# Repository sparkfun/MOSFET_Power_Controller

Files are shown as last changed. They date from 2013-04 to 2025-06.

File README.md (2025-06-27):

MOSFET Power Controller
=======================

[MOSFET Power Controller  
*MOSFET Power Controller(PRT-11214)*](https://www.sparkfun.com/products/11214)

This MOSFET Power Controller board allows you to turn a high current battery power supply on and off via microcontroller inputs. 

Repository Contents
-------------------
* **/Hardware** - All Eagle design files (.brd, .sch)
* **/Production** - Test bed files and production panel files

License Information
-------------------
The hardware is released under [Creative Commons Share-alike 3.0](http://creativecommons.org/licenses/by-sa/3.0/).

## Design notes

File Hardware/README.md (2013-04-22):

# What Are these Files?

The .sch and .brd files hare are Eagle CAD schematic and PCB design files.

These files were created with Eagle 6.3.0, you'll need Eagle 6.3 or later to open them up. There is a free, lite, version of Eagle available from [cadsoftusa.com](cadsoftusa.com).

# License

This product is open source! These Eagle files are released under the Creative Commons Share-Alike Attribution license ([CC BY-SA 3.0](http://creativecommons.org/licenses/by-sa/3.0/us/)).

Please use, reuse, and modify these files as you see fit. Please maintain attribution and release anything derivative under the same license.

- Your friends at SparkFun.

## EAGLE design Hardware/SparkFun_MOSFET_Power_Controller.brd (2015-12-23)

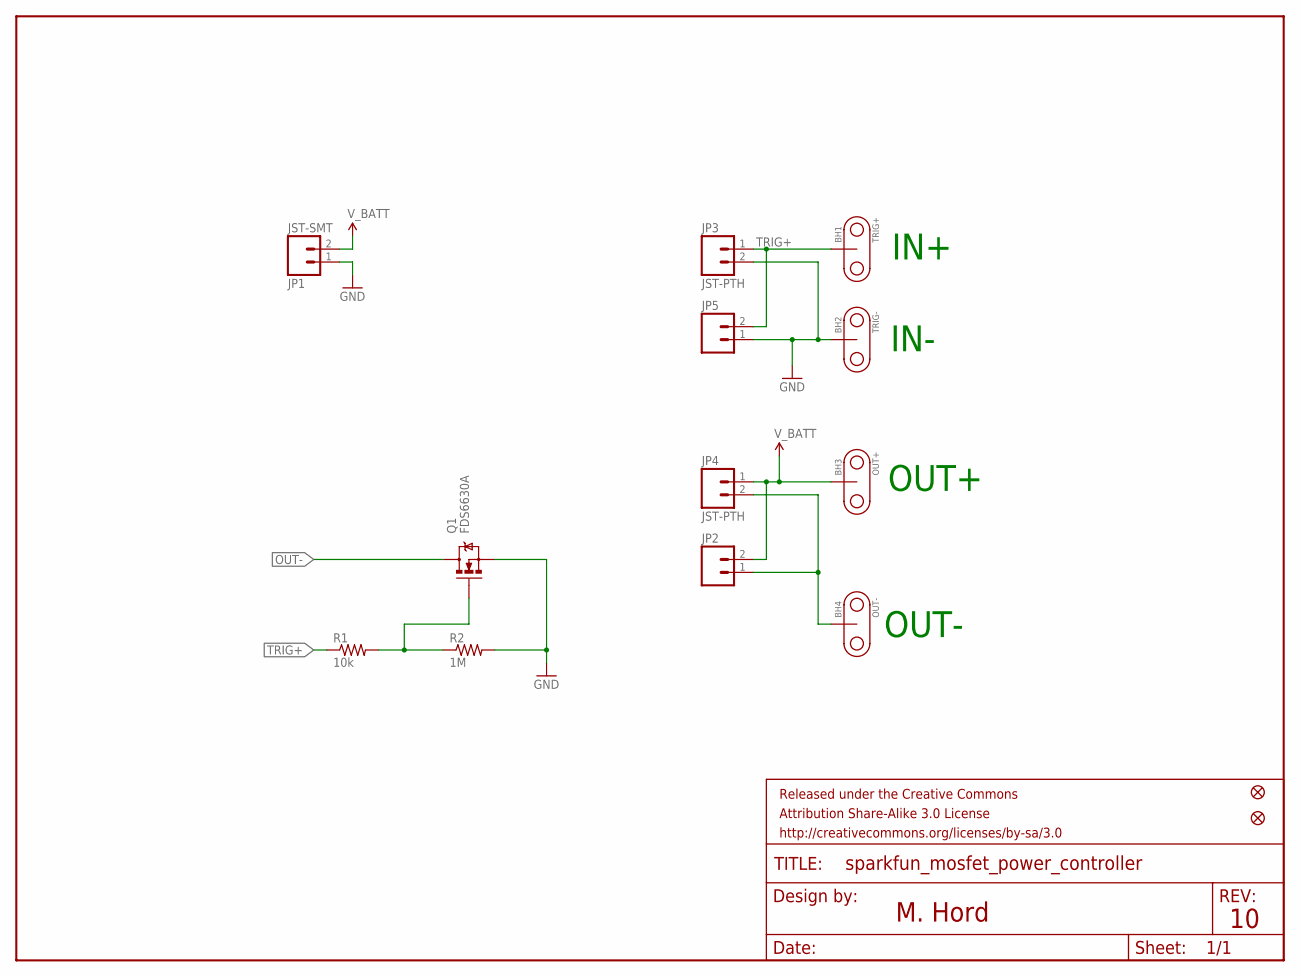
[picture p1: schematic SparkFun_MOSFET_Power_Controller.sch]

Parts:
BH1: TRIG+; BUTTONHOLE
BH2: TRIG-; BUTTONHOLE
BH3: OUT+; BUTTONHOLE
BH4: OUT-; BUTTONHOLE
FRAME1: FRAME-LETTER; CREATIVE_COMMONS
JP1: JST-SMT; JST-2-SMD
JP2, JP5: M02PTH; 1X02
JP3, JP4: JST-PTH; JST-2-PTH-NS
JP6, JP7: FIDUCIALUFIDUCIAL; MICRO-FIDUCIAL
Q1: FDS6630A; SO08
R1: 10k; 0402-RES
R2: 1M; 0402-RES

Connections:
GND: BH2.P$1, JP1.1 (2), JP3.2, JP5.1, Q1.1 (S), Q1.2 (S), Q1.3 (S), R2.2
unnamed: Q1.4 (G), R1.2, R2.1
OUT-: BH4.P$1, JP2.1, JP4.2, Q1.5 (D), Q1.6 (D), Q1.7 (D), Q1.8 (D)
TRIG+: BH1.P$1, JP3.1, JP5.2, R1.1
V_BATT: BH3.P$1, JP1.2 (1), JP2.2, JP4.1

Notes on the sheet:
M. Hord
IN+
IN-
OUT+
OUT-

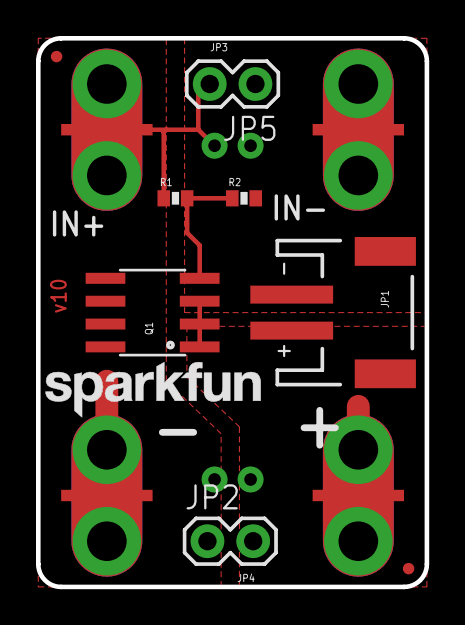
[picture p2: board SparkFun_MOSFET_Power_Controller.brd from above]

Board: 2 copper layers, 21.6 x 30.5 mm, 15 parts (0 on the bottom side), 5 nets.

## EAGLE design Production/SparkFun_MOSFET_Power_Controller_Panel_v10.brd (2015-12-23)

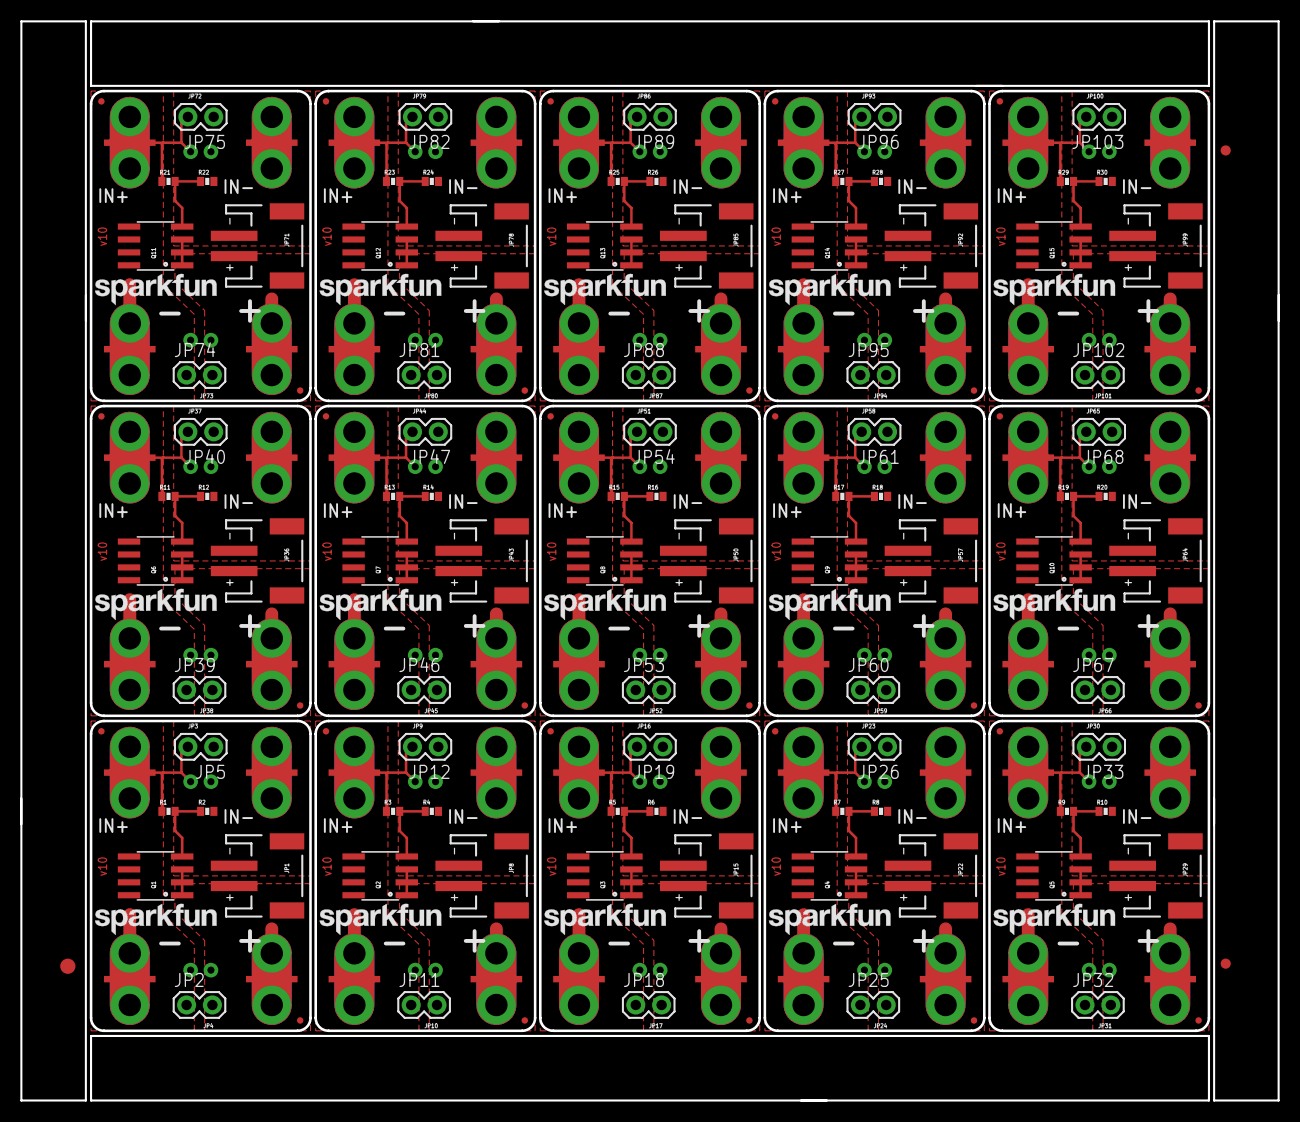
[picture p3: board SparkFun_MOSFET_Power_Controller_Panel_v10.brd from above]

Board: 2 copper layers, 123.7 x 106.2 mm, 213 parts (0 on the bottom side), 75 nets.

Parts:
BH1, BH5, BH9, BH13, BH17, BH21, BH25, BH29, BH33, BH37, BH41, BH45, BH49, BH53, BH57: TRIG+; BUTTONHOLE
BH2, BH6, BH10, BH14, BH18, BH22, BH26, BH30, BH34, BH38, BH42, BH46, BH50, BH54, BH58: TRIG-; BUTTONHOLE
BH3, BH7, BH11, BH15, BH19, BH23, BH27, BH31, BH35, BH39, BH43, BH47, BH51, BH55, BH59: OUT+; BUTTONHOLE
BH4, BH8, BH12, BH16, BH20, BH24, BH28, BH32, BH36, BH40, BH44, BH48, BH52, BH56, BH60: OUT-; BUTTONHOLE
E$1: FIDUCIAL-1.5X3
E$5, E$6: FIDUCIAL-1X2
JP1, JP8, JP15, JP22, JP29, JP36, JP43, JP50, JP57, JP64, JP71, JP78, JP85, JP92, JP99: JST-SMT; JST-2-SMD
JP2, JP5, JP11, JP12, JP18, JP19, JP25, JP26, JP32, JP33, JP39, JP40, JP46, JP47, JP53, JP54, JP60, JP61, JP67, JP68, JP74, JP75, JP81, JP82, JP88, JP89, JP95, JP96, JP102, JP103: 1X02
JP3, JP4, JP9, JP10, JP16, JP17, JP23, JP24, JP30, JP31, JP37, JP38, JP44, JP45, JP51, JP52, JP58, JP59, JP65, JP66, JP72, JP73, JP79, JP80, JP86, JP87, JP93, JP94, JP100, JP101: JST-PTH; JST-2-PTH-NS
JP6, JP7, JP13, JP14, JP20, JP21, JP27, JP28, JP34, JP35, JP41, JP42, JP48, JP49, JP55, JP56, JP62, JP63, JP69, JP70, JP76, JP77, JP83, JP84, JP90, JP91, JP97, JP98, JP104, JP105: FIDUCIALUFIDUCIAL; MICRO-FIDUCIAL
Q1, Q2, Q3, Q4, Q5, Q6, Q7, Q8, Q9, Q10, Q11, Q12, Q13, Q14, Q15: FDS6630A; SO08
R1, R3, R5, R7, R9, R11, R13, R15, R17, R19, R21, R23, R25, R27, R29: 10k; 0402-RES
R2, R4, R6, R8, R10, R12, R14, R16, R18, R20, R22, R24, R26, R28, R30: 1M; 0402-RES

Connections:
GND: BH2.P$1, JP1.1, JP3.2, JP5.1, Q1.1, Q1.2, Q1.3, R2.2
GND1: BH6.P$1, JP8.1, JP9.2, JP12.1, Q2.1, Q2.2, Q2.3, R4.2
GND2: BH10.P$1, JP15.1, JP16.2, JP19.1, Q3.1, Q3.2, Q3.3, R6.2
GND3: BH14.P$1, JP22.1, JP23.2, JP26.1, Q4.1, Q4.2, Q4.3, R8.2
GND4: BH18.P$1, JP29.1, JP30.2, JP33.1, Q5.1, Q5.2, Q5.3, R10.2
GND5: BH22.P$1, JP36.1, JP37.2, JP40.1, Q6.1, Q6.2, Q6.3, R12.2
GND6: BH26.P$1, JP43.1, JP44.2, JP47.1, Q7.1, Q7.2, Q7.3, R14.2
GND7: BH30.P$1, JP50.1, JP51.2, JP54.1, Q8.1, Q8.2, Q8.3, R16.2
GND8: BH34.P$1, JP57.1, JP58.2, JP61.1, Q9.1, Q9.2, Q9.3, R18.2
GND9: BH38.P$1, JP64.1, JP65.2, JP68.1, Q10.1, Q10.2, Q10.3, R20.2
GND10: BH42.P$1, JP71.1, JP72.2, JP75.1, Q11.1, Q11.2, Q11.3, R22.2
GND11: BH46.P$1, JP78.1, JP79.2, JP82.1, Q12.1, Q12.2, Q12.3, R24.2
GND12: BH50.P$1, JP85.1, JP86.2, JP89.1, Q13.1, Q13.2, Q13.3, R26.2
GND13: BH54.P$1, JP92.1, JP93.2, JP96.1, Q14.1, Q14.2, Q14.3, R28.2
GND14: BH58.P$1, JP99.1, JP100.2, JP103.1, Q15.1, Q15.2, Q15.3, R30.2
unnamed: Q1.4, R1.2, R2.1
unnamed: Q2.4, R3.2, R4.1
unnamed: Q3.4, R5.2, R6.1
unnamed: Q4.4, R7.2, R8.1
unnamed: Q5.4, R9.2, R10.1
unnamed: Q6.4, R11.2, R12.1
unnamed: Q7.4, R13.2, R14.1
unnamed: Q8.4, R15.2, R16.1
unnamed: Q9.4, R17.2, R18.1
unnamed: Q10.4, R19.2, R20.1
unnamed: Q11.4, R21.2, R22.1
unnamed: Q12.4, R23.2, R24.1
unnamed: Q13.4, R25.2, R26.1
unnamed: Q14.4, R27.2, R28.1
unnamed: Q15.4, R29.2, R30.1
OUT-: BH4.P$1, JP2.1, JP4.2, Q1.5, Q1.6, Q1.7, Q1.8
OUT-1: BH8.P$1, JP10.2, JP11.1, Q2.5, Q2.6, Q2.7, Q2.8
OUT-2: BH12.P$1, JP17.2, JP18.1, Q3.5, Q3.6, Q3.7, Q3.8
OUT-3: BH16.P$1, JP24.2, JP25.1, Q4.5, Q4.6, Q4.7, Q4.8
OUT-4: BH20.P$1, JP31.2, JP32.1, Q5.5, Q5.6, Q5.7, Q5.8
OUT-5: BH24.P$1, JP38.2, JP39.1, Q6.5, Q6.6, Q6.7, Q6.8
OUT-6: BH28.P$1, JP45.2, JP46.1, Q7.5, Q7.6, Q7.7, Q7.8
OUT-7: BH32.P$1, JP52.2, JP53.1, Q8.5, Q8.6, Q8.7, Q8.8
OUT-8: BH36.P$1, JP59.2, JP60.1, Q9.5, Q9.6, Q9.7, Q9.8
OUT-9: BH40.P$1, JP66.2, JP67.1, Q10.5, Q10.6, Q10.7, Q10.8
OUT-10: BH44.P$1, JP73.2, JP74.1, Q11.5, Q11.6, Q11.7, Q11.8
OUT-11: BH48.P$1, JP80.2, JP81.1, Q12.5, Q12.6, Q12.7, Q12.8
OUT-12: BH52.P$1, JP87.2, JP88.1, Q13.5, Q13.6, Q13.7, Q13.8
OUT-13: BH56.P$1, JP94.2, JP95.1, Q14.5, Q14.6, Q14.7, Q14.8
OUT-14: BH60.P$1, JP101.2, JP102.1, Q15.5, Q15.6, Q15.7, Q15.8
TRIG+: BH1.P$1, JP3.1, JP5.2, R1.1
TRIG+1: BH5.P$1, JP9.1, JP12.2, R3.1
TRIG+2: BH9.P$1, JP16.1, JP19.2, R5.1
TRIG+3: BH13.P$1, JP23.1, JP26.2, R7.1
TRIG+4: BH17.P$1, JP30.1, JP33.2, R9.1
TRIG+5: BH21.P$1, JP37.1, JP40.2, R11.1
TRIG+6: BH25.P$1, JP44.1, JP47.2, R13.1
TRIG+7: BH29.P$1, JP51.1, JP54.2, R15.1
TRIG+8: BH33.P$1, JP58.1, JP61.2, R17.1
TRIG+9: BH37.P$1, JP65.1, JP68.2, R19.1
TRIG+10: BH41.P$1, JP72.1, JP75.2, R21.1
TRIG+11: BH45.P$1, JP79.1, JP82.2, R23.1
TRIG+12: BH49.P$1, JP86.1, JP89.2, R25.1
TRIG+13: BH53.P$1, JP93.1, JP96.2, R27.1
TRIG+14: BH57.P$1, JP100.1, JP103.2, R29.1
V_BATT: BH3.P$1, JP1.2, JP2.2, JP4.1
V_BATT1: BH7.P$1, JP8.2, JP10.1, JP11.2
V_BATT2: BH11.P$1, JP15.2, JP17.1, JP18.2
V_BATT3: BH15.P$1, JP22.2, JP24.1, JP25.2
V_BATT4: BH19.P$1, JP29.2, JP31.1, JP32.2
V_BATT5: BH23.P$1, JP36.2, JP38.1, JP39.2
V_BATT6: BH27.P$1, JP43.2, JP45.1, JP46.2
V_BATT7: BH31.P$1, JP50.2, JP52.1, JP53.2
V_BATT8: BH35.P$1, JP57.2, JP59.1, JP60.2
V_BATT9: BH39.P$1, JP64.2, JP66.1, JP67.2
V_BATT10: BH43.P$1, JP71.2, JP73.1, JP74.2
V_BATT11: BH47.P$1, JP78.2, JP80.1, JP81.2
V_BATT12: BH51.P$1, JP85.2, JP87.1, JP88.2
V_BATT13: BH55.P$1, JP92.2, JP94.1, JP95.2
V_BATT14: BH59.P$1, JP99.2, JP101.1, JP102.2

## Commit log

2013-01-22 Initial commit- these are v02 files, as run in the last prototype phase.
    [MOSFET_driver.brd, MOSFET_driver.sch]
2013-01-28 Swap source and drain pins.
    The original schematic symbol isn't clear on which pins are drain
    and which are source, so I screwed it up. The MOSFET was always
    conducting through the body diode.
    This version fixes it and should be considered for release.
    [MOSFET_driver.brd, MOSFET_driver.sch]
2013-02-25 RedBoard release v10 Rotate MOSFET 180 degrees. Fixed flame on silk overlapping MOSFET. Added .1" headers at either end.
    [MOSFET_driver.brd, MOSFET_driver.sch]
2013-02-28 Production readied
    added fiducial reference points and created panel for manufacture
    [MOSFET_driver Panel v10.brd, MOSFET_driver.brd, MOSFET_driver.sch]
2013-04-22 Update repo structure and add a README with licensing.
    [MOSFET_driver Panel v10.brd]
2015-05-06 Updating file names, adding gitattributes
    [SparkFun_MOSFET_Power_Controller.brd, SparkFun_MOSFET_Power_Controller.sch]
2015-12-23 created new v10 panel
    [MOSFET_driver Panel v10.brd, SparkFun_MOSFET_Power_Controller.brd, SparkFun_MOSFET_Power_Controller_Panel_v10.brd]

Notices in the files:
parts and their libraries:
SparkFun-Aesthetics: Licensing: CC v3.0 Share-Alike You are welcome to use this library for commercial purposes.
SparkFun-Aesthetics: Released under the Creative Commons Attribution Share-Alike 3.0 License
